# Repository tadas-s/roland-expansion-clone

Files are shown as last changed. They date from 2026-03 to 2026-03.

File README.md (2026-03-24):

# DIY Roland JV-1080 expansion card

Recently I restored a [Roland XP-60][1] synth for a friend. It's a digital sample
based synth with possibility of expanding sample set with up to 4 expansion
cards. And, while looking at service manual I got carried away a little...
Those expansion cards have a pretty straightforward interface - 8 bit data bus,
20 bit address bus, a few chip enable pins. Looked like something very DIYable.

Needless to say, I'm not the first one to notice it. Someone made copies of available
expansions and reverse engineered the format. [SRJV][3] is a script collection
to create/manipulate those ROMs.

# Schematic

For my own clone I used AM29F016D-70E4C flash chips. These are obsolete but still
widely available on eBay.

I included extra headers to expose flash WE, RESET for in-circuit programming,
but that part is untested - I ended up pre-programming chips before soldering.

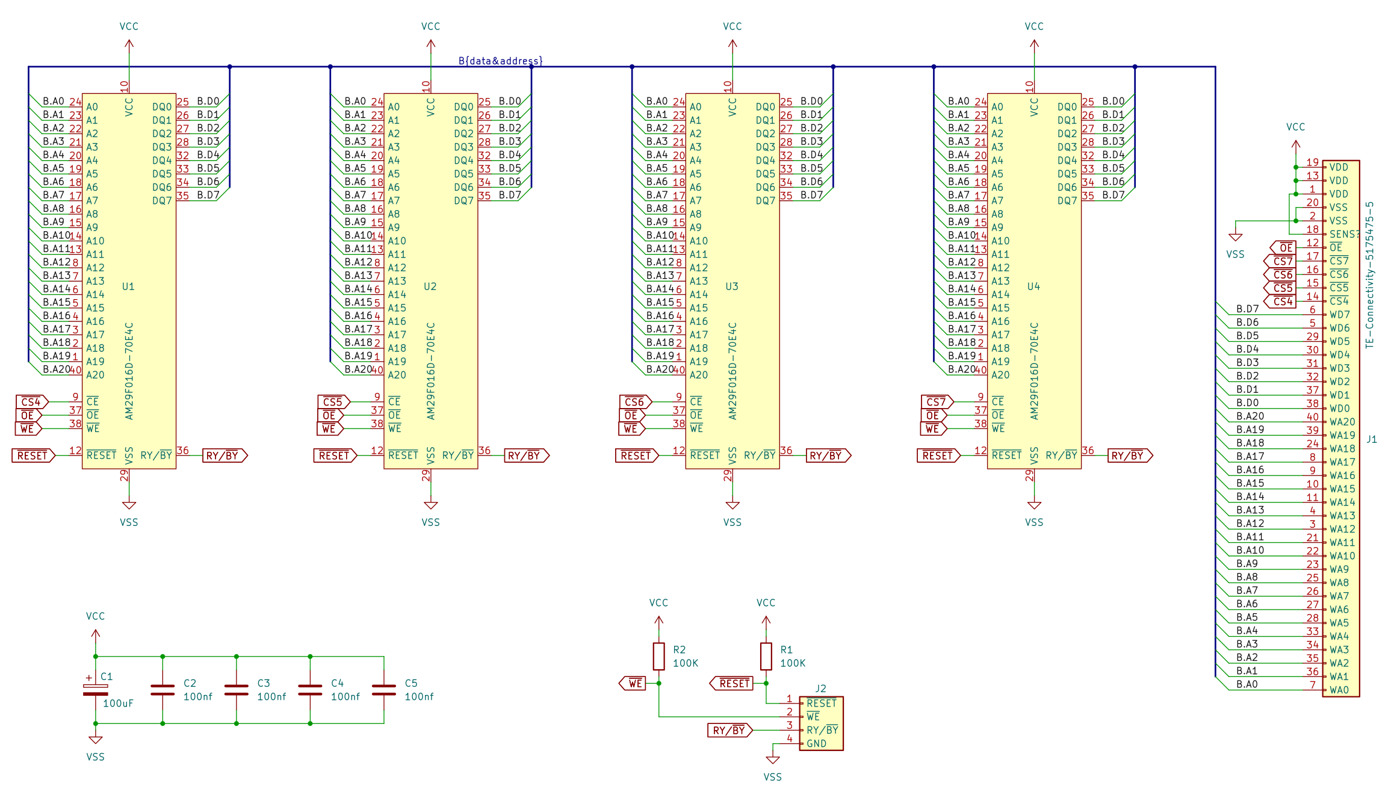
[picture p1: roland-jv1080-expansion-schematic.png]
Roland JV-1080 expansion schematic


# PCB

Did not want to spend too much time on layout so went with a more expensive
4 layer board.

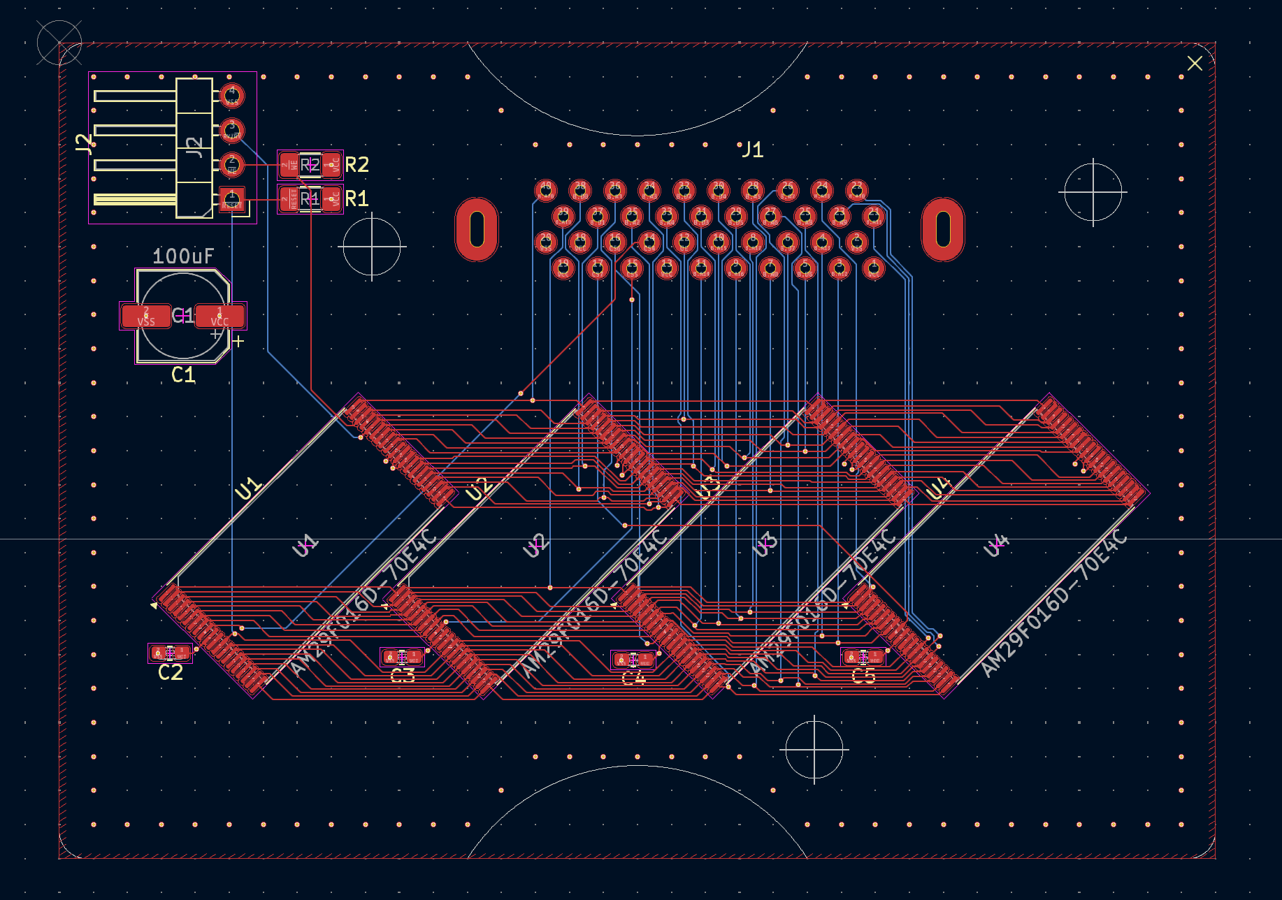
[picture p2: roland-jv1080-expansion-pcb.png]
Roland JV-1080 expansion pcb


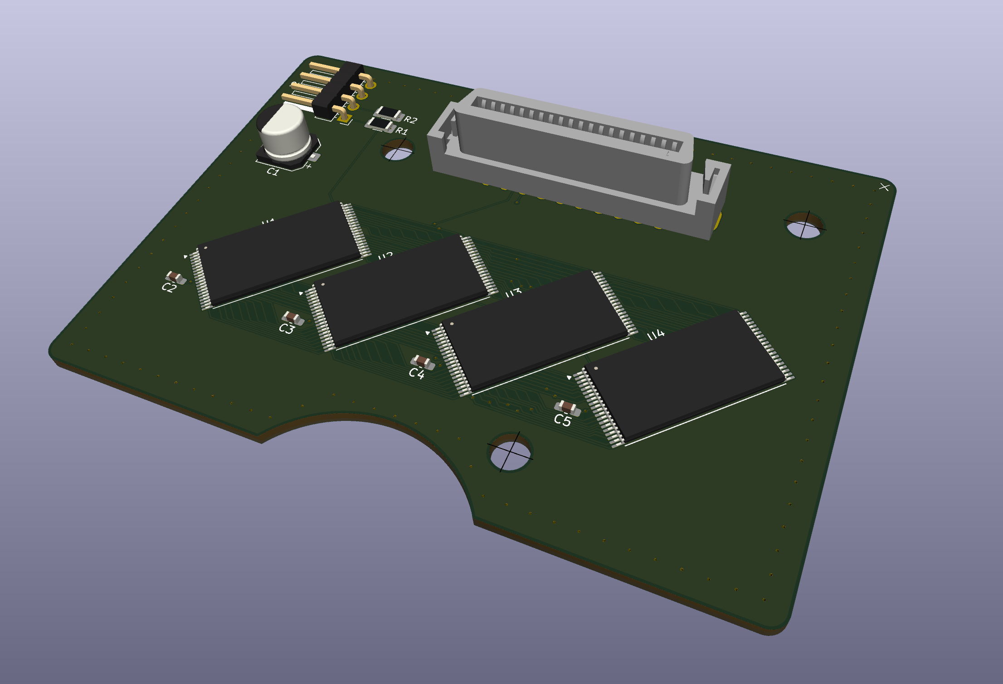
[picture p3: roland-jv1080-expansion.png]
Roland JV-1080 expansion


# Assembled board

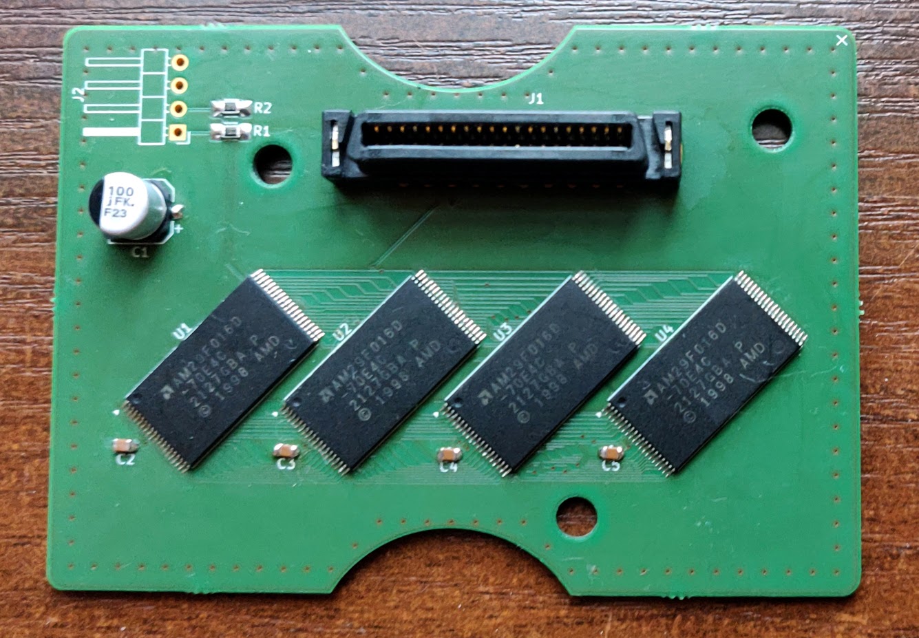
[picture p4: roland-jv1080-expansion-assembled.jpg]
Roland JV-1080 expansion assembled


Two expansions installed next to one original from Roland:

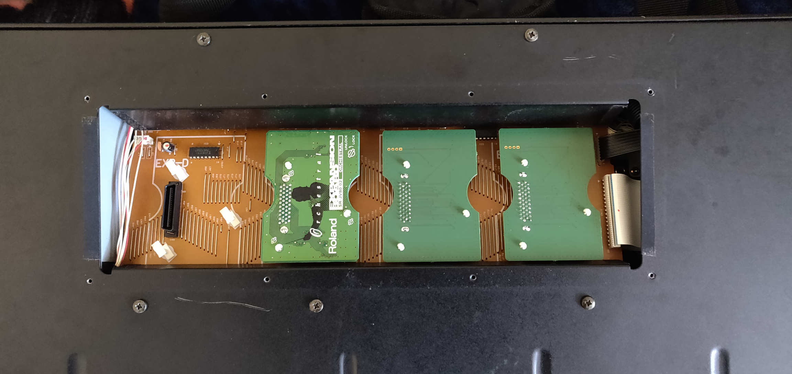
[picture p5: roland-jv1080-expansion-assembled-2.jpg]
Roland JV-1080 expansion assembled


[1]: https://www.vintagesynth.com/roland/xp-60
[2]: https://en.wikipedia.org/wiki/Roland_JV-1080
[3]: https://github.com/PythonBlue/SRJV

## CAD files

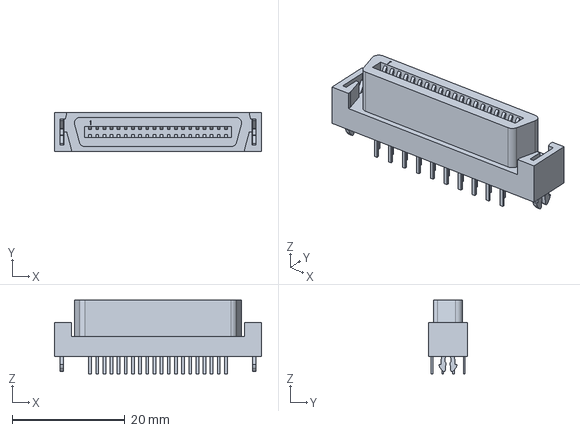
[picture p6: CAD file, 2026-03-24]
c-5175475-05-o-3d.stp
36.8 x 7.00 x 13.1 mm

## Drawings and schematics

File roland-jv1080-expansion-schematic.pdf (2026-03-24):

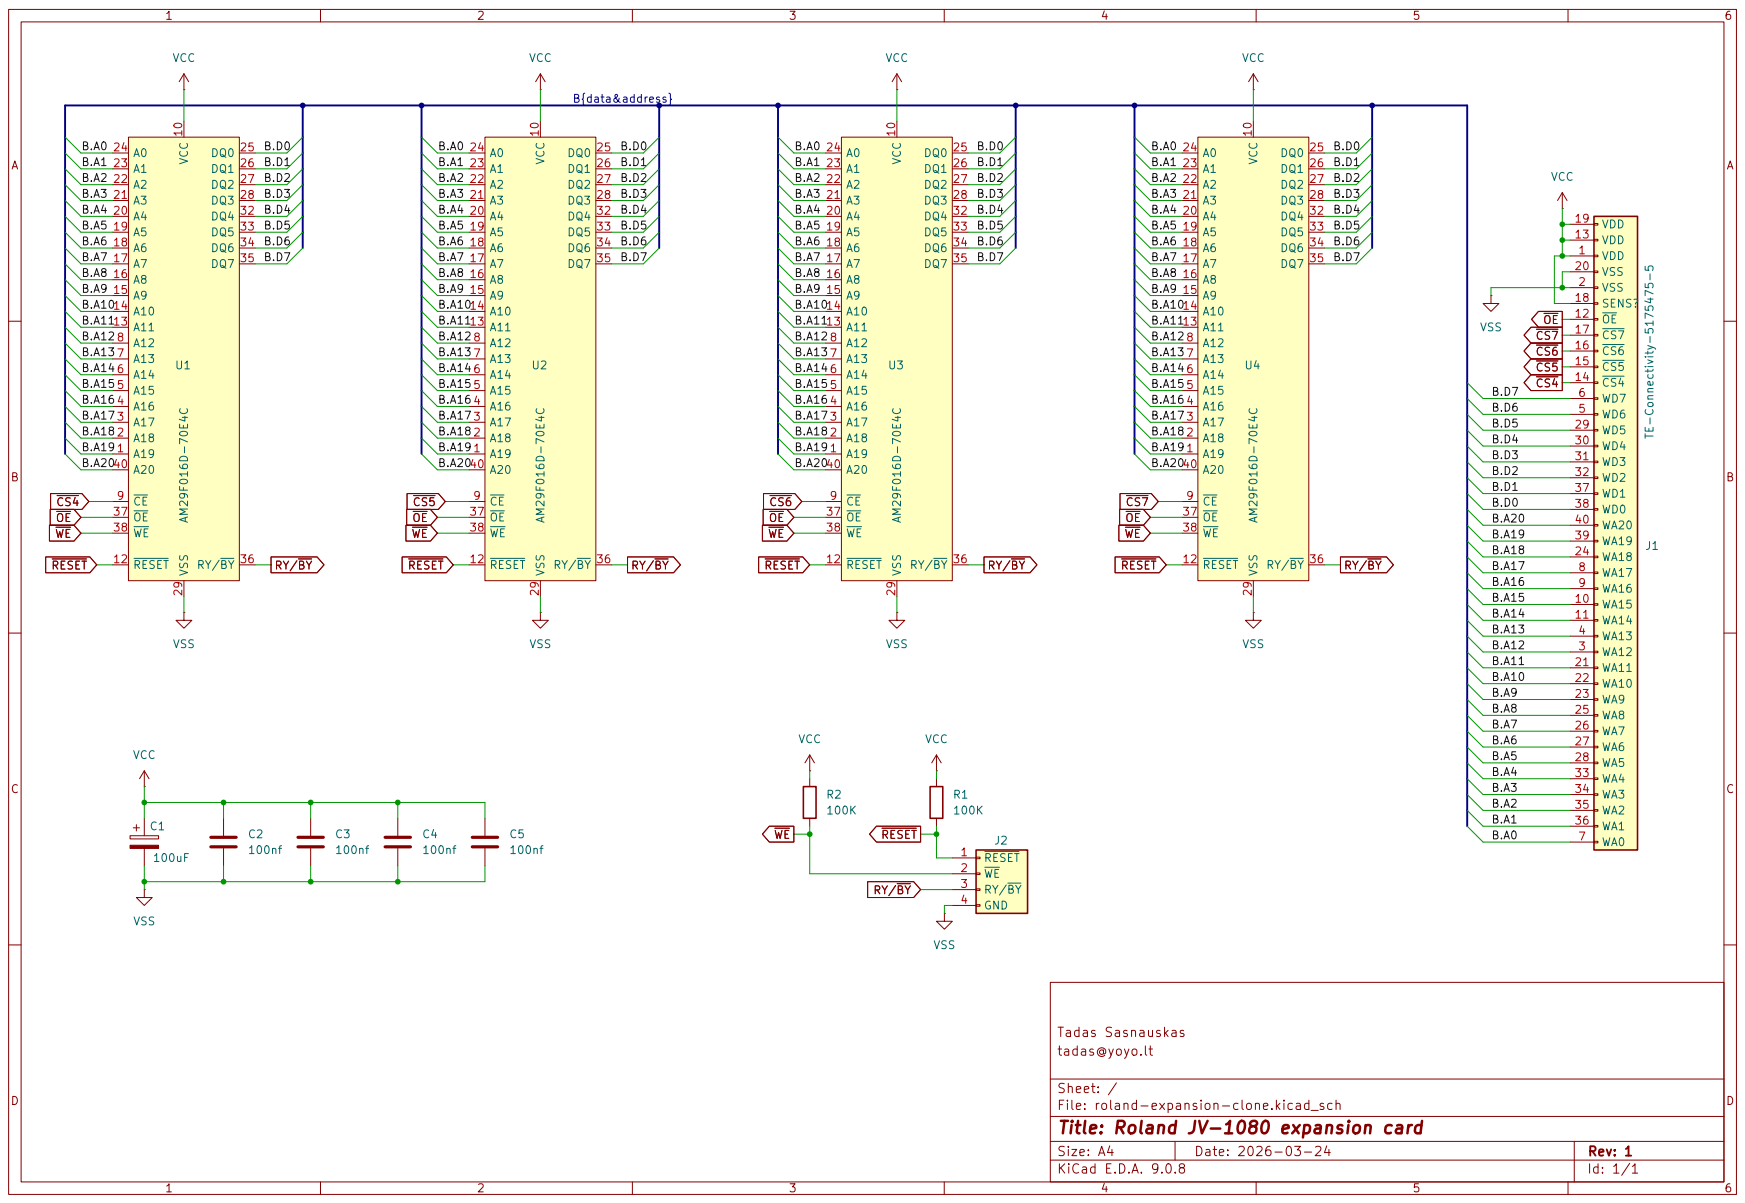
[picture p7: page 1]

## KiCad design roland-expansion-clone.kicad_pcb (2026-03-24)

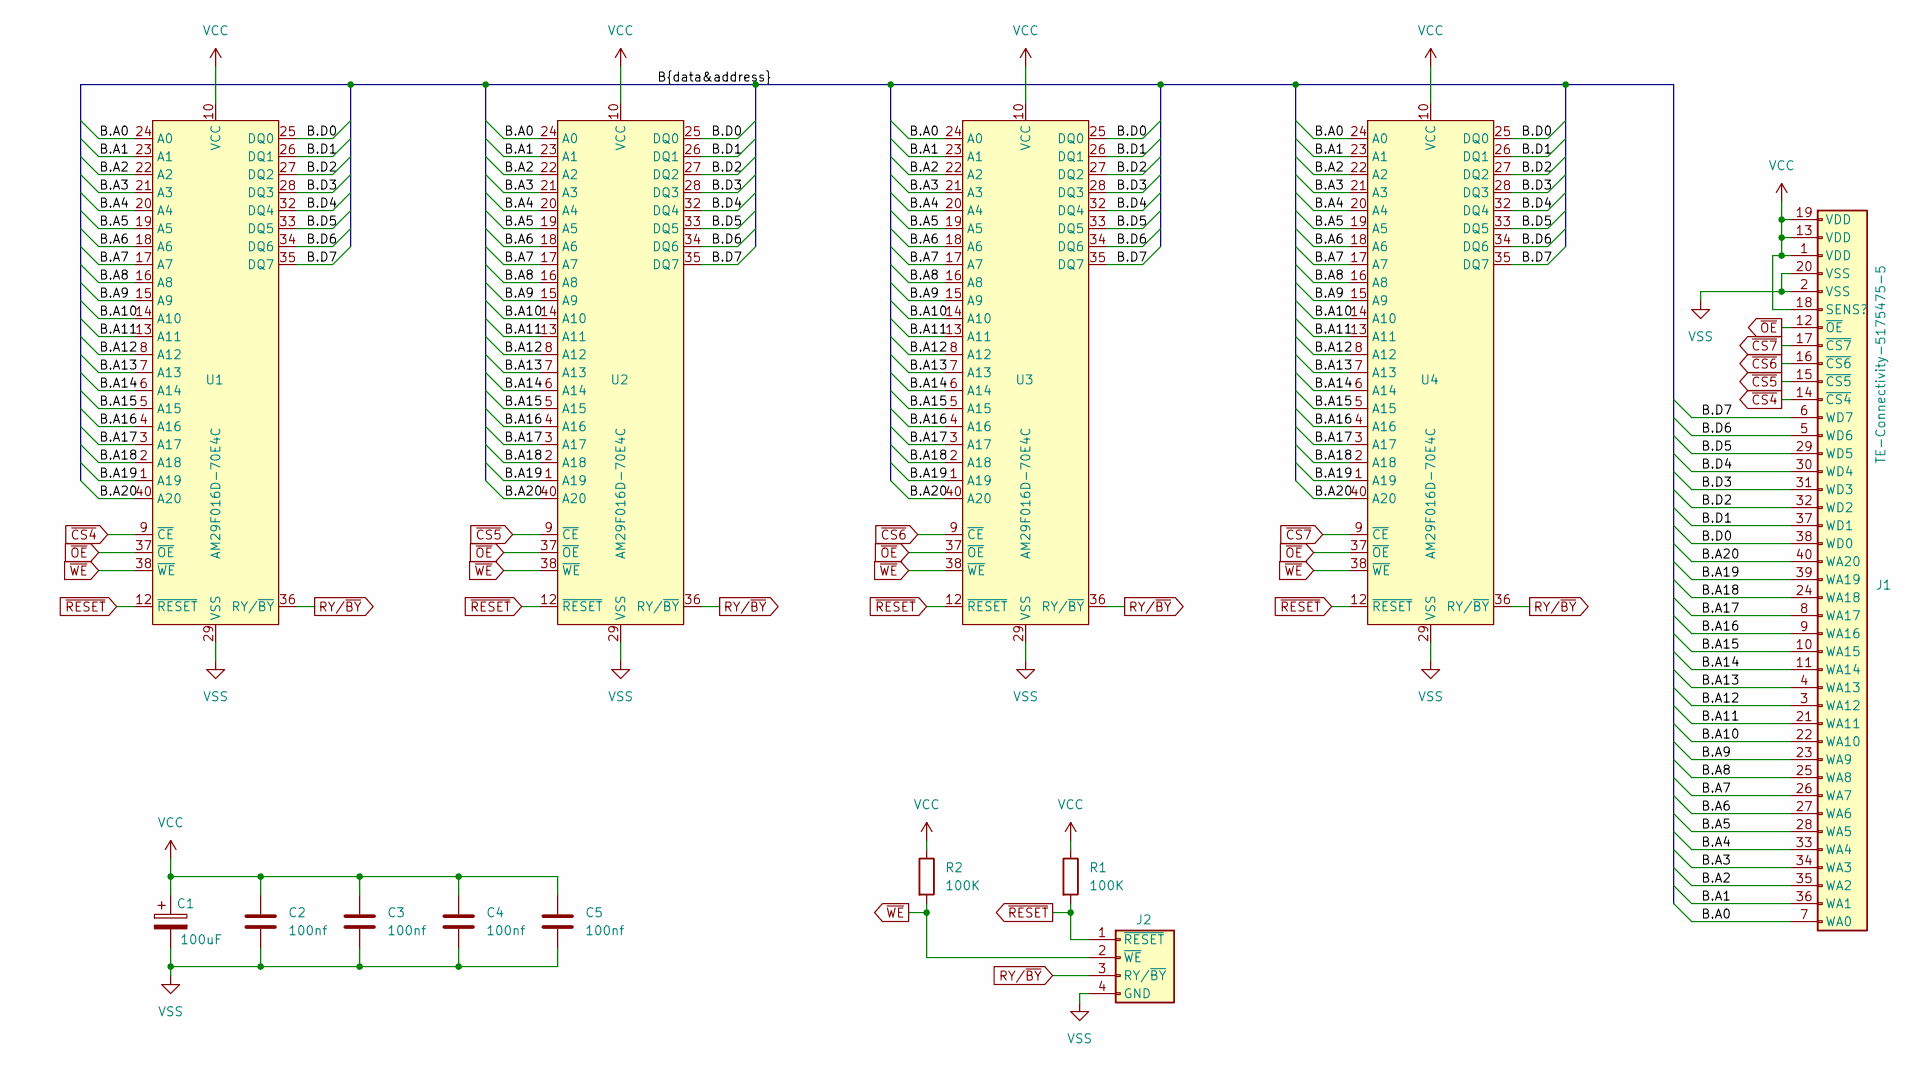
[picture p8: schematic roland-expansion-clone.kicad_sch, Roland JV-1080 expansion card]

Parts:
C1: 100uF; CP_Elec_6.3x5.7
C2, C3, C4, C5: 100nf; C_0603_1608Metric_Pad1.08x0.95mm_HandSolder
J1: TE-Connectivity-5175475-5
J2: Conn_01x04; PinHeader_1x04_P2.54mm_Horizontal
R1, R2: 100K; R_1206_3216Metric_Pad1.30x1.75mm_HandSolder
U1, U2, U3, U4: AM29F016D-70E4C; TSOP-I-40_18.4x10mm_P0.5mm

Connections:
/B.A0: J1.7 (WA0), U1.24 (A0), U2.24 (A0), U3.24 (A0), U4.24 (A0)
/B.A1: J1.36 (WA1), U1.23 (A1), U2.23 (A1), U3.23 (A1), U4.23 (A1)
/B.A2: J1.35 (WA2), U1.22 (A2), U2.22 (A2), U3.22 (A2), U4.22 (A2)
/B.A3: J1.34 (WA3), U1.21 (A3), U2.21 (A3), U3.21 (A3), U4.21 (A3)
/B.A4: J1.33 (WA4), U1.20 (A4), U2.20 (A4), U3.20 (A4), U4.20 (A4)
/B.A5: J1.28 (WA5), U1.19 (A5), U2.19 (A5), U3.19 (A5), U4.19 (A5)
/B.A6: J1.27 (WA6), U1.18 (A6), U2.18 (A6), U3.18 (A6), U4.18 (A6)
/B.A7: J1.26 (WA7), U1.17 (A7), U2.17 (A7), U3.17 (A7), U4.17 (A7)
/B.A8: J1.25 (WA8), U1.16 (A8), U2.16 (A8), U3.16 (A8), U4.16 (A8)
/B.A9: J1.23 (WA9), U1.15 (A9), U2.15 (A9), U3.15 (A9), U4.15 (A9)
/B.A10: J1.22 (WA10), U1.14 (A10), U2.14 (A10), U3.14 (A10), U4.14 (A10)
/B.A11: J1.21 (WA11), U1.13 (A11), U2.13 (A11), U3.13 (A11), U4.13 (A11)
/B.A12: J1.3 (WA12), U1.8 (A12), U2.8 (A12), U3.8 (A12), U4.8 (A12)
/B.A13: J1.4 (WA13), U1.7 (A13), U2.7 (A13), U3.7 (A13), U4.7 (A13)
/B.A14: J1.11 (WA14), U1.6 (A14), U2.6 (A14), U3.6 (A14), U4.6 (A14)
/B.A15: J1.10 (WA15), U1.5 (A15), U2.5 (A15), U3.5 (A15), U4.5 (A15)
/B.A16: J1.9 (WA16), U1.4 (A16), U2.4 (A16), U3.4 (A16), U4.4 (A16)
/B.A17: J1.8 (WA17), U1.3 (A17), U2.3 (A17), U3.3 (A17), U4.3 (A17)
/B.A18: J1.24 (WA18), U1.2 (A18), U2.2 (A18), U3.2 (A18), U4.2 (A18)
/B.A19: J1.39 (WA19), U1.1 (A19), U2.1 (A19), U3.1 (A19), U4.1 (A19)
/B.A20: J1.40 (WA20), U1.40 (A20), U2.40 (A20), U3.40 (A20), U4.40 (A20)
/B.D0: J1.38 (WD0), U1.25 (DQ0), U2.25 (DQ0), U3.25 (DQ0), U4.25 (DQ0)
/B.D1: J1.37 (WD1), U1.26 (DQ1), U2.26 (DQ1), U3.26 (DQ1), U4.26 (DQ1)
/B.D2: J1.32 (WD2), U1.27 (DQ2), U2.27 (DQ2), U3.27 (DQ2), U4.27 (DQ2)
/B.D3: J1.31 (WD3), U1.28 (DQ3), U2.28 (DQ3), U3.28 (DQ3), U4.28 (DQ3)
/B.D4: J1.30 (WD4), U1.32 (DQ4), U2.32 (DQ4), U3.32 (DQ4), U4.32 (DQ4)
/B.D5: J1.29 (WD5), U1.33 (DQ5), U2.33 (DQ5), U3.33 (DQ5), U4.33 (DQ5)
/B.D6: J1.5 (WD6), U1.34 (DQ6), U2.34 (DQ6), U3.34 (DQ6), U4.34 (DQ6)
/B.D7: J1.6 (WD7), U1.35 (DQ7), U2.35 (DQ7), U3.35 (DQ7), U4.35 (DQ7)
RY/~BY: J2.3 (RY/~BY), U1.36 (RY/~BY), U2.36 (RY/~BY), U3.36 (RY/~BY), U4.36 (RY/~BY)
VCC: C1.1, C2.1, C3.1, C4.1, C5.1, J1.1 (VDD), J1.13 (VDD), J1.18 (SENS?), J1.19 (VDD), R1.1, R2.1, U1.10 (VCC), U1.31 (VCC), U2.10 (VCC), U2.31 (VCC), U3.10 (VCC), U3.31 (VCC), U4.10 (VCC), U4.31 (VCC)
VSS: C1.2, C2.2, C3.2, C4.2, C5.2, J1.2 (VSS), J1.20 (VSS), J2.4 (GND), U1.29 (VSS), U1.30 (VSS), U2.29 (VSS), U2.30 (VSS), U3.29 (VSS), U3.30 (VSS), U4.29 (VSS), U4.30 (VSS)
~CS4: J1.14 (~CS4), U1.9 (~CE)
~CS5: J1.15 (~CS5), U2.9 (~CE)
~CS6: J1.16 (~CS6), U3.9 (~CE)
~CS7: J1.17 (~CS7), U4.9 (~CE)
~OE: J1.12 (~OE), U1.37 (~OE), U2.37 (~OE), U3.37 (~OE), U4.37 (~OE)
~RESET: J2.1 (~RESET), R1.2, U1.12 (~RESET), U2.12 (~RESET), U3.12 (~RESET), U4.12 (~RESET)
~WE: J2.2 (~WE), R2.2, U1.38 (~WE), U2.38 (~WE), U3.38 (~WE), U4.38 (~WE)

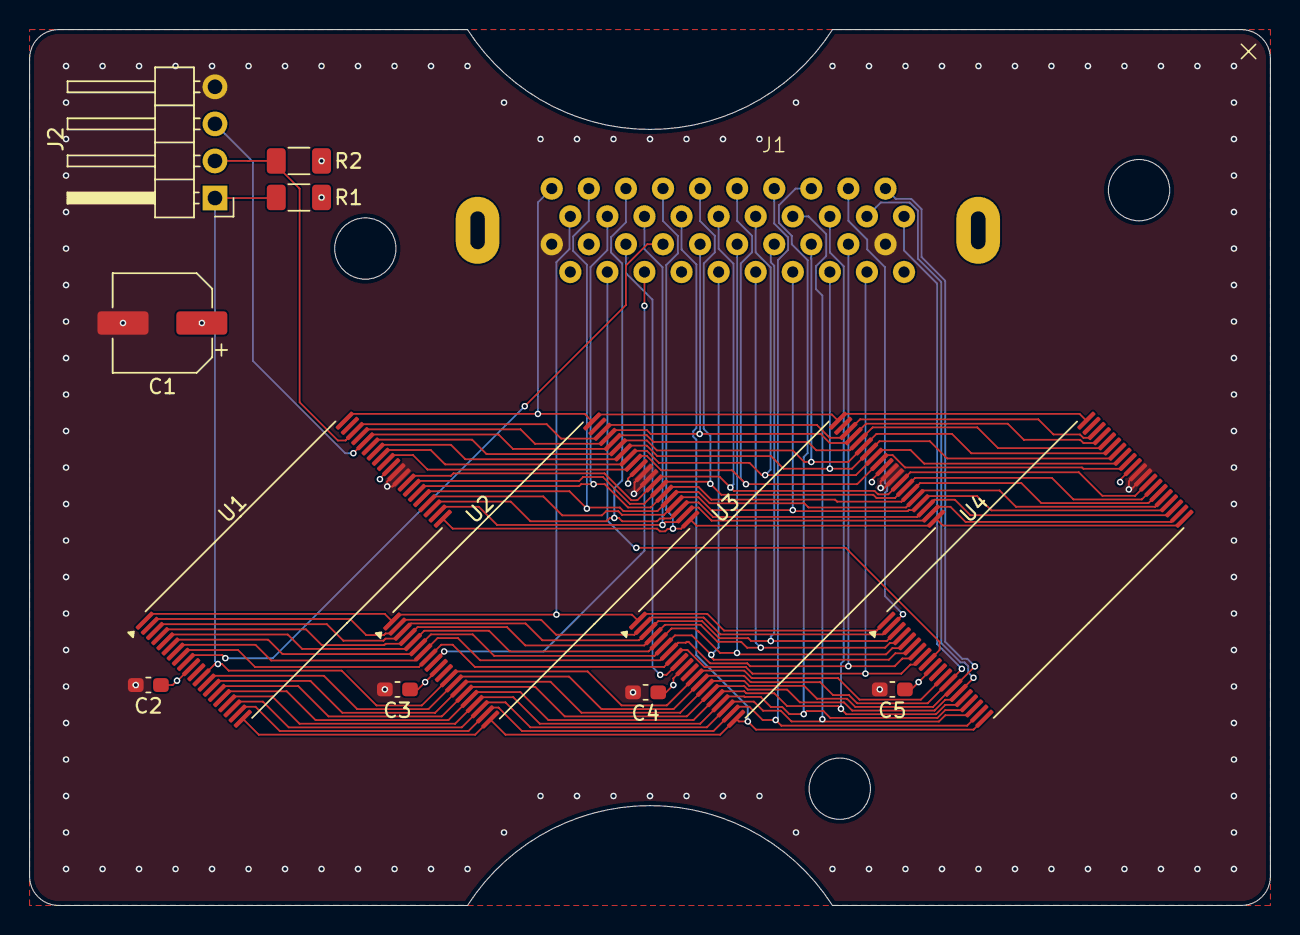
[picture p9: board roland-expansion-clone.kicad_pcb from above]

Board: 4 copper layers, 85.0 x 60.0 mm, 13 parts (0 on the bottom side), 39 nets.
